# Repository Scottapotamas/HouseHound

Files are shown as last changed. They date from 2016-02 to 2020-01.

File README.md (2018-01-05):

# HouseHound

Home datalogging and display system for DIY (TCP/IP based) sensor nodes and web facing display.

I use a Raspberry Pi running OpenHAB 2 as the main hub, and then a bunch of stateless microcontroller nodes around the house interface over wifi and ethernet.

This repo contains all the applicable files for hardware, fimware, or notes for setup for each of the projects to consolidate everything, but any combination of parts should work alone. This repo is more for self-documenting the project than anything else, as keeping track of configuration is tedious.

# WeatherStation

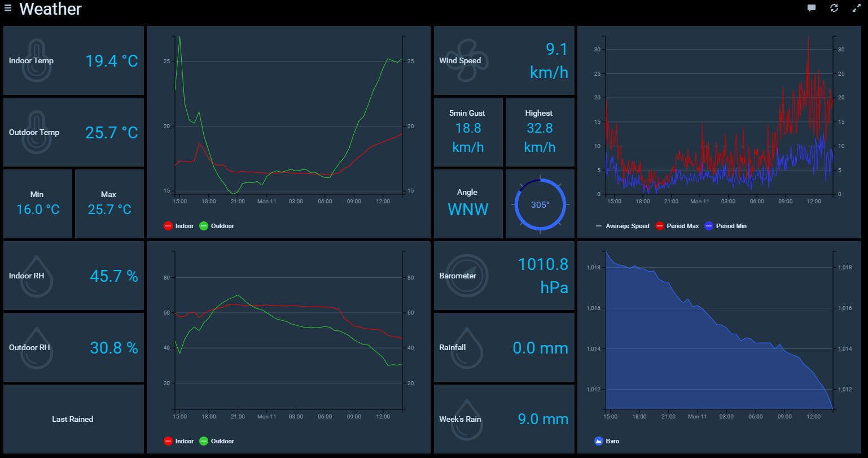
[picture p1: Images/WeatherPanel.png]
Weather WeatherStation View


Large and high feature set weather monitoring to measure the following info:
- Temperature
- Humidity
- Barometric Pressure
- Wind Speed
- Wind Direction
- Rainfall

Reference data is also scraped from the Australian BoM page for our closest station for temp/humidity references. From watching the BoM reference against local sensors, my system tracks the 'reference' data within 1°C and ~5°% RH over most days, well within the realm of local weather differences due to ~3km distance from that station.

## TempHumidityNodes

Several of these are sitting around the house to provide 2-zone indoor monitoring, and outdoor sensing.

Small and low cost Wifi Weather node for data collection, also sent to a local OpenHAB instance.

- Uses a particle photon wifi based microcontroller.
- Temperature and Humidity Sensor, includes additional spare IO for future expansion.
- Uses MQTT to send averaged temperature and humidity data to the mosquitto server.

## WeatherStation

This sits on a pole mounted to the roof. Leverages a Particle Photon wireless microcontroller and the Sparkfun weather shield to simplify connections to the hardware. Uses interrupts for rain/wind speed events, and polls other sensors periodically.

Sensors are sampled at 100ms, and averaged across the time between messages to the openHAB server for persistance and processing.

We send temperature, humidity, rainfall accumulated, windspeed and wind direction every few seconds, and track long term averages of wind speed and baro for lower noise. The short term values are shown for more responsive dashboards, while the internally averaged min/max values are logged for graphing and stats use.

MQTT is once again used to send the values to the mosquitto broker, which the OpenHAB instance subscribes to.

# PowerMonitor

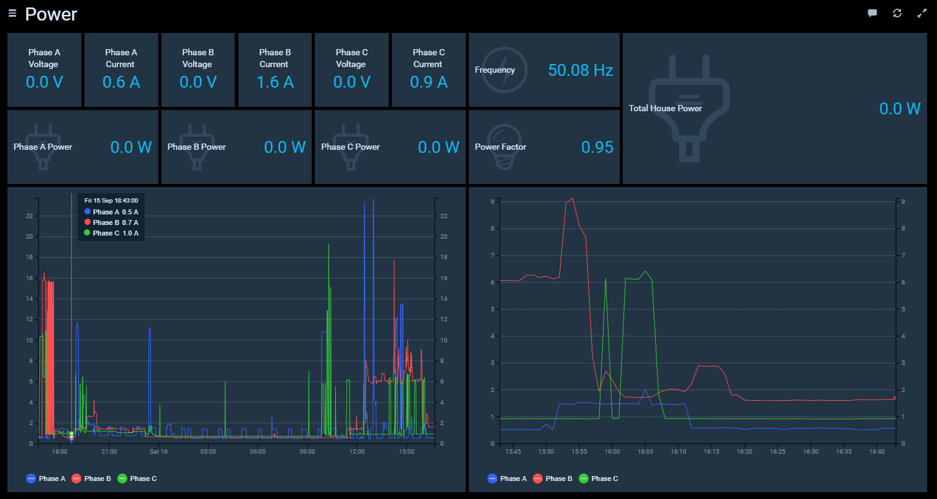
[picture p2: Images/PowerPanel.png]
Power PowerStation View


A bunch of current transducers and 3 12VAC transformers in the sub-distro board. This allows for monitoring of the voltage and current of each phase (have 3-phase installed).

Sends data to local MQTT broker as done with other sensors.

Measures:
- 3-phase current 
- 3-phase Voltage
- Power factor
- Frequency

# Airconditioner Controller

IN PROGRESS

Replacement control module for the evaporative aircon unit. Provides better information display, finer grained control of hardware, intelligent modes.

I pull data from a local OpenHAB instance for another weather node in the house, and scrapped internet weather info.
HAB node also provides some level of control for home automation.

Uses following hardware:
- Adafruit HUZZAH ESP-12E module
- HDC1000 temp and humidity sensor
- BMP280 pressure sensor
- SSD1306 2.7inch OLED (on i2c)
- WS2812 (RGBW) as a status lamp

# WaterMonitor

Sensors to monitor the status of the rain water tanks and pump system.
With a known tank level and flow information over a daily/weekly time period it should be possible to predict time-to-empty.

Measures:
- Water level in the tank using a submerged pressure sensor.
- Water flow from tank (TODO).

## Tank Level

Uses a $60 Aliexpress sourced 'stainless' 4-20mA pressure sensor, a particle photon and a ADS1115 ADC breakout from adafruit as these were just spares I had on hand. The particle and ADC are powered with a small pololu 500mA 5V SMPS which was spare.

Threw a couple of 100uF electro's on the supplies for stability, and put it in a waterproof box for outdoor use with an old phone charger to supply 12ish volts.

A gland was used to draw the pressure sensor's cable from the tank.

Because the sensor is a 4-20mA loop device, I use the ADC in differential mode across a 220R resistor wit

Eventually I'd like to add the ability to switch the feed valve from the rain collection sump to allow user controllable bypass of the tanks, so the first few mm of rain are purged and we don't put the accumulated dirt from the roof into the tanks. After manual implementation, may consider doing this automatically or semi-autonomously based on rain data.

A AC powered rotary valve with DN40 fittings was purchased from Aliexpress to test with this.

# Other OpenHAB integration

The openhab server uses HabPanel for most visualisation, which is viewed on a older Microsoft surface in fullscreen mode.

The server performs hourly speedtest.net tests and logs/graphs down/up/ping. SMNP integration to read wifi/nas utilisation is also planned.

Todo:

- Integrate with Chromecasts for control over music/tv outputs.
- Connect the burglar alarm RS232 to gain access to PIR and state information?
- Add solenoid control to the side gate

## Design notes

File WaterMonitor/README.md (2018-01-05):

# WaterMonitor

Uses particle photon, ADS1115 ADC and 220R resistor as burden for the 4-20mA pressure sensor from Aliexpress.

Samples every 250ms, averages samples over 5 seconds and publishes to the MQTT server every 5 seconds.

This is overkill and over-accurate in every aspect.

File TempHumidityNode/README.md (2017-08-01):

# Temp and Humidity Node

This node is built with a Particle Photon and a Si7021 i2c based temperature and humidity IC.

Uses MQTT to report to the MQTT/Openhab server.

These boards are design to be as simple and fast to deploy as possible. Idea is to drop one at each end of the house, and one or two outside.

# Self-heating (or lack of)

The particle photon generates lots of heat when connected to wifi. This causes a self-heating effect on the weathershield which uses the same sensor.

As these are wired directly, the sensor is on about 100mm of free cable which will allow flexibility in isolating the sensor from the photon.

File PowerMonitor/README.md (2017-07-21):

# PowerMonitor

This node is built with a Particle Photon and a ATM90E36 board bought from whatnick's tindie page.

Uses MQTT to report to the MQTT/Openhab server.

This was a fast turn-key approach to sampling 3 phase power and current, and should be better than the previous install.

Bits borrowed from https://github.com/whatnick/ATM90E36_Arduino with modifications for Photon SPI.

# Calibration

Need to calibrate against Fluke current clamp. Left it at work by accident...

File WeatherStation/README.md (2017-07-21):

# WeatherStation

This node is built with a Particle Photon and a Sparkfun Weather shield.

Uses MQTT to report to the MQTT/Openhab server.

This was a fast turn-key approach to sampling wind, rainfall and wind direction.

Code is somewhat verbose. Bits borrowed from https://github.com/rpurser47/weatherstation with some restructuring.

# Self-heating

The particle photon generates lots of heat when connected to wifi. This causes a self-heating effect which is measured by the temp sensor.

I attempted to reduce the effects by manually controlling the photon's wifi and putting it to sleep between report periods.
Turns out the ubiquiti wifi access point doesn't like a device re-connecting every 5 seconds for days, so this ended up not working.

The sensor's data is really just used for the external sensors on the roof, and barometric pressure.

# TODO

There is a lot of cross-coupled noise between the wind speed and rain reed-switch lines. The actual sensors are on a very long cable.

Need to put a scope on the lines, determine suitable software debounce parameters or beef up the sparkfun board circuitry. Would have been nice for Sparkfun to drive the switches at VCC level, then translate back to 3v3 for the micro.

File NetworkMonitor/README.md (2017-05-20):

#Network Monitoring

The plan is to do regular speedtests to watch down/up speed over time, and monitor internal hardware.

# Internet

It seems internet tests are already a solved issue:
https://community.openhab.org/t/speedtest-cli-internet-up-downlink-measurement-integration/7611

This has been implemeted.

# SNMP Network

The modem, ubiquiti wireless AP, and QNAP nas all support SNMP monitoring.

Ideally wireless speeds and states, along with storage and qnap load would be shown.

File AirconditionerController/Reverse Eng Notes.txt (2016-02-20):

# Evaporative Airconditioner Controller replacement/upgrade Project

#Existing controller
It has buttons for on/off, mode, fan, water pump, timer, and leds above them to denote the status.

The unit connects to the controller with 4 wires.
GND, 5.7V (why?), the fan and pump control lines. 
Uses a 5 pin 2.54mm pitch connector, similar to KK, but locking tab in center with no keying.

Pump is 0V, or 1.8V when on
Fan is pulled high at off (to 5.7V) 
Fanspeed is controlled with a voltage output 
	(inversely proportional to fanspeed) between 1.1v (slow) and 3.2v (pretty fast, adjustable on PCB with pot)

# Hardware

We use the ESP8266 for wifi control and as the microcontroller for this airconditioner controller. 
I will be using one of the adafruit HUZZAH boards which includes a 3v3 reg, reset button and broken out pins to make life a little easier.

# Sensing
Temp+Humiditiy sensor on i2c
Barometric pressure on i2c

# Output
2.7" OLED monochrome display driven over SPI or i2c or parallel (not in this project)
WS2812 as a status lamp

# Input
4 buttons - momentary

To drive the airconditioners, the following is used:

Fan:
	DAC on the ESP is used with a opamp for level shifting
	0-3v3 from the ESP analog output, we use a gain of 1.7 to provide a maximum 5.7v output

Water Pump:
	Driven by a digital IO on the ESP. 
	LOW = 0V
	HIGH = 3v3 from ESP -> 1.8. Probably use voltage divider, or a fet if needed.

5.7V is connected to the ESP which has onboard 3v3 regulator.

# User Interface

Mode is displayed in the top left of the display	

		Off 			Nothing is happening, idle mode
		Automatic 		Looks at temperature indoors and outdoors, and controls aircon based on delta.
		Manual			User controls the unit manually

	Web connected control doesn't have a distinct mode, but just allows an override of the existing mode and settings.

Fan Speed is displayed on the second to bottom line, on the left
	Has fan symbol, followed by % fan speed.
		if fan is off, replace % with text OFF

Pump status is displayed on the bottom line, on the left
	Water drop symbol, followed by text ON, OFF or PRIME

# Status Lamp

Aircon Off
	Displays colour wheel set by the temperature delta between inside and outside.
		ie, the colour is green at equilibrium
			goes blue when colder outside
			goes red when warmer outside

Aircon On
	Fan Only
		Green solid
	Water pump only
		Pulsing Blue
	Fan with Water
		Blue solid, gets brighter with higher fan speed

Error
	Could not connect to wifi
		Pulsing white light

	Could not find/update NTP time
		Triple white blink, then wait a bit.

# Behaviour

At startup, connect to the known wifi network. Display IP address on screen for 5 seconds once connected.
Poll NTP server for most recent time, report status to monitoring sofware as required.

We have a deadband on the temperature delta between outside and indoors, and make automatic decisions based on season

	Summer
		if temperature > deadband
			Do nothing
		if temperature < deadband
			Bring colder air into house
	Winter
		if temperature > deadband
			Bring warm air through
		if temperature < deadband
			Do nothing

HOT_THRESHOLD_DEGREES	Outside temperature is hotter than inside, threshold
COLD_THRESHOLD_DEGREES	Outside temperature is colder than inside, threshold

Fan Speed will be expressed as a percentage from 0 to 100%
The function setFanSpeed(int percentage) will calculate the output voltage from a %, to drive the DAC output with a opamp.

Voltage ranges for output as follows
FAN_SPEED_MIN	3.2
FAN_SPEED_MAX	1.1

# Function prototypes

int main () {
	
	setupIO();
	initHardware();

	initWifi();
	updateTime();
	initHAB();

	while(1) {
		main();

	}

	return 0;
}

void setupIO() {
	//set pinmodes etc

	return;
}

void initHardware() {
	//init display
	//init neopixels
	//init i2c
	//contact and check for i2c sensors

	return;
}

void initWifi() {
	
	//attempt to connect to known hotspot

	//confirm connection to network by pinging gateway

	//confirm connection to internet by pinging dns server

	return;
}

void updateTime() {
	//contact NTP time server

	//if failed, contact second server

	//set time

	return;
}

void initHAB() {
	//setup local HomeAutomation stuff as required

	return;
}

void loop() {

	//run different speed loops
	everyLoop();

	if(loopCount == 2) {	//every third loop
		mediumLoop();
	}

	if(loopCount == 10) {	//every 10th loop
		slowLoop();
	}

	if(long time condition) {	//only occasionally
		glacialLoop();
	})

	//reset anything for next loop
}

void everyLoop() {
	//read button states
	//other critical monitoring tasks

	//run through the state machine?

	return;
}

void mediumLoop() {
	//update the display
	//update pixels

	return;
}

void slowLoop() {
	//get temperature

	return;
}

void glacialLoop() {
	updateTime();
	checkOnlineWeather();

	return;
}

void setFanSpeed(int percentage) {
	//we drive the analog output to set the speed from 3.2 to 1.1V

	float driveVoltage = FAN_VOLTAGE_OFF;	

	//map percentage to voltage between 1.1 and 3.2, inversely proportional
	//apply gain of 1.7 
	//desired voltage output
	//clamp to min/max to prevent damage

	//map voltage output into 10bit
	//analogWrite(outputVal)

	return;
}

void setPump(bool enable) {
	//water pump takes 0 for off, 1.8v for on.
	
	//digitalWrite(PUMP_PIN, enable);

	if(fanSpeed > 5) {	//fan on
		//start the pump or leave it on, log as needed.
		//state = wetfan;
	} else {	//fan not running
		//we are priming the pump first
		//state = priming;
	}

	return;
}
]

void readSensors() {
	
	//get temperature

	//get humidity

	//get barometric pressure

	//push this new data to HAB server

	return;
}

void getExternalTemp() {
	//contact HAB server and request a temperature from a different node
	//save to internal variable

	return;
}

void checkOnlineWeather() {
	//contact/poll some service for forcast weather
	//update structure as required

	return;
}

void drawDisplay() {
	
	//draw current mode text
	drawFanItem();
	drawPumpItem();

	//draw current time

	//draw time since start
	//draw scheduled off time

	switch(tempPage) {	//draw the corresponding temperature data
		case 0:
			//draw text "Inside"

			//draw internal temp, humidity

			break;
		case 1:
			//draw text "Exterior"

			//draw local external temp, humidity

			break;

		case 2:
			//draw text "Internet"

			//draw internet temp/humidity

			break;
	}

	return;
}

void drawFanItem() {
	
	//draw fan icon

	if(fanSpeed > 5) {
		//percentage text

	} else {
		//off text

	}

	return;
}

void drawPumpItem() {
	
	//draw water drop symbol

	//draw pump status

	return;
}

void updateStatusLED(int ledTypeStruct) {
	
	switch(ledTypeStruct) {
		case 0:		//off

		break;

		case 1:		//auto mode
			//lamp changes temperature based on temp differential outside house

		break;

		case 2.1:		//manual mode fan only
			//light is green, brightness controlled by fan speed.

		break;

		case 2.2:		//manual mode water only
			//priming pump, pulse blue

		break;

		case 2.3:		//manual mode fan with water
			//blue light, brightness controlled by fan speed.

		break;

		case 3.1:		//waiting for scheduled start
			//pulse white

		break;

		case 3.2:		//running until scheduled stop
			//white

		break;

		default:	//something went wrong
			//flash white error code

		break;

	}

	return;
}

void setBrightnessByPercent(int percentage) {
	//we compensate for linear/log luma output

	//https://ledshield.wordpress.com/2012/11/13/led-brightness-to-your-eye-gamma-correction-no/

	brightness_mod = magic multiplier value;
	
	return;
}

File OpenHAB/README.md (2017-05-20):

# OpenHAB Notes

Setup a OpenHAB 2 install on a Pi2.

# General notes for myself

- Changed the timezone and local to Adelaide etc.
- Changed the default password and samba password, still using openhabian as the user
- Configured mosquitto as the MQTT broker
- Tested the mqtt server using MQTT.fx on windows

- Assigned the pi to 192.168.1.100 via DHCP reservation.
- Mount the samba share and edit config files as required. WebUI seems painful to use.

- Hostname is househound now instead of openhabian.
- Port 8080 has the webUI for OpenHAB.

- In the mqtt.cfg config file, 192.168.1.100:8083 was set as the broker URI for the mosquitto install done earlier.

# Persistance Setup

Using mySQL for persistence of data. Database is Openhab, user is openhab with standard password.

- Temp/Humidity and Pressure are logged at 30min interval.
- Rainfall is logged on every update as each update represents non-zero rainfall over the sampling period.
- A series of persistance periods are added. Need to work out what to use for each dataset.

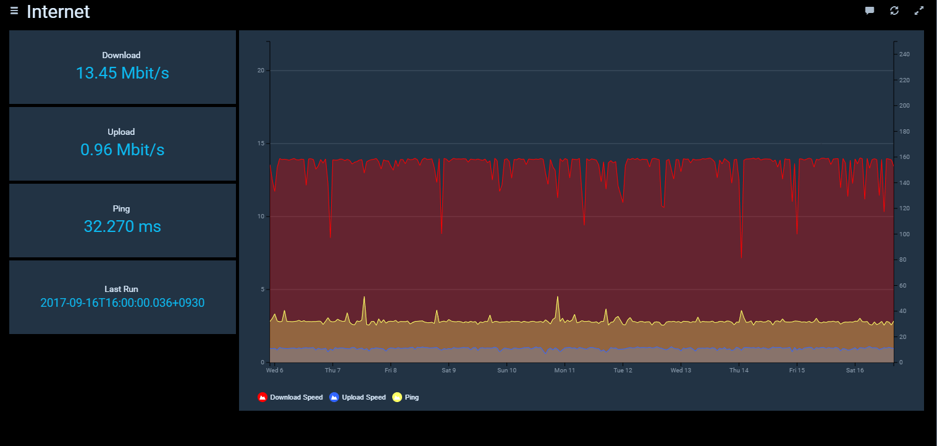
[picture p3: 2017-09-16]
Images/InternetPanel.png

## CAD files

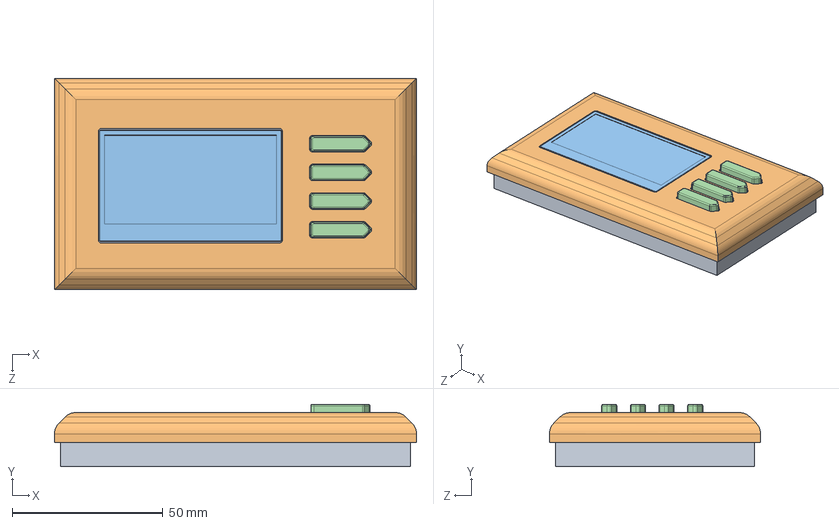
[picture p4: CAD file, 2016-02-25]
AirconditionerController/CAD/Controller Assembly.SLDASM
120.0 x 20.7 x 70.0 mm
Backing Piece
Faceplate
Display
Button x 4

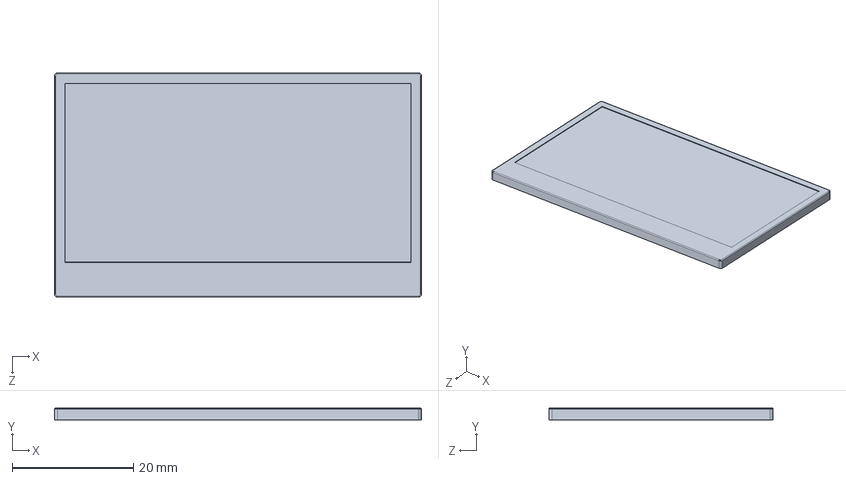
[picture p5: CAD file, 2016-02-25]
AirconditionerController/CAD/Display.SLDPRT
60.5 x 2.00 x 37.0 mm

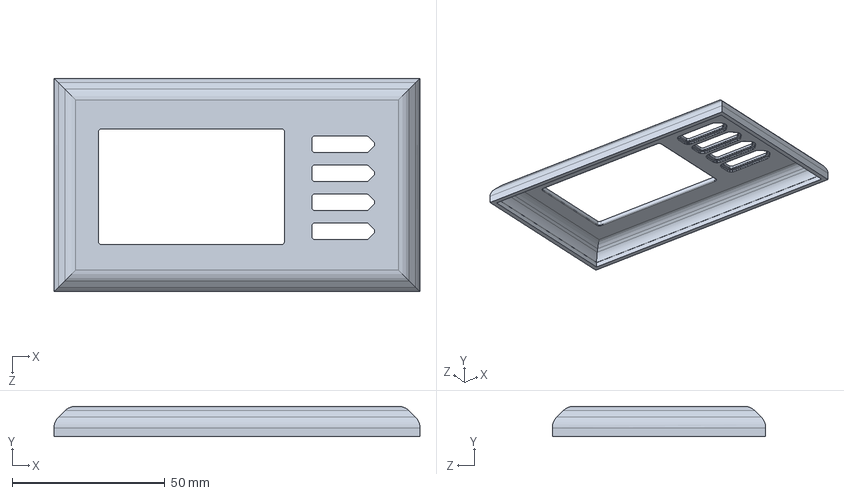
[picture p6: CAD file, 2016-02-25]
AirconditionerController/CAD/Faceplate.SLDPRT
120.0 x 10.0 x 70.0 mm

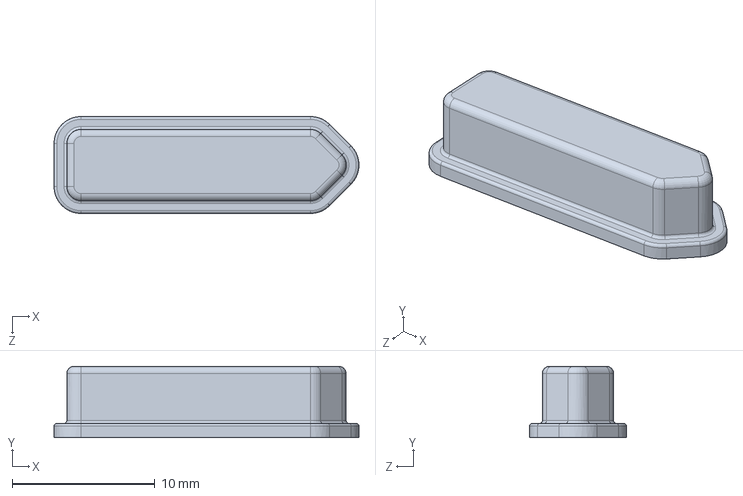
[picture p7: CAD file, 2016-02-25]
AirconditionerController/CAD/Button.SLDPRT
21.4 x 5.00 x 6.80 mm

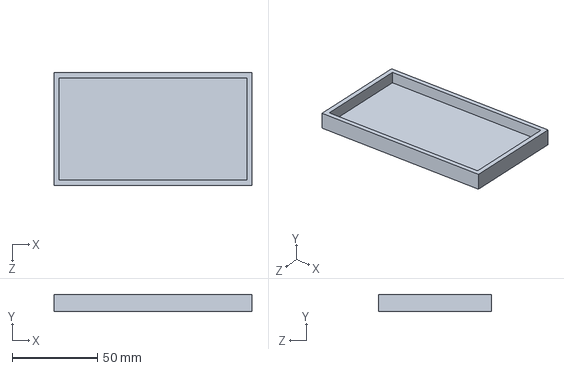
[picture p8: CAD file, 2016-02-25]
AirconditionerController/CAD/Backing Piece.SLDPRT
116.0 x 10.0 x 66.0 mm

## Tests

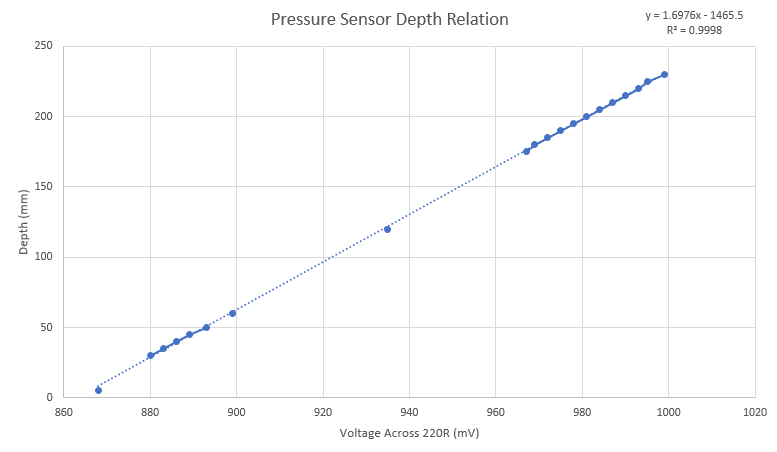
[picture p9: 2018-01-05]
Images/DepthCalibrationCurve.PNG

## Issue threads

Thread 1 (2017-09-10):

Rain detection isn't filtered properly

Scottapotamas, 2017-09-10:
Rain detections with Sparkfun weather stick (windspeed/direction and rain gauge) were firing random events of noise causing phantom rainfall measures.

Scope on the D2 and D3 pins of the photon, watching for falling edges on D2 (rain).

Some noise would occasionally cause a ~10-20us low spike with lots of ringing, and the falling edges are caught by the interrupt on the micro. Subsequent falling edges in this fake event weren't measured due to the debounce on the interrupt event handler, but on reflection, the actual duration of the 'switch closure' has no lower bound.

Solution: watch or monitor interrupt on falling AND rising edge, and ensure that the pulse is longer than a few milliseconds to remove these occasional noisy events.

Check to see if the photon can have rising/falling/change interupts on the same pin, otherwise, connect to two pins and use different interrupt handlers, or just sample the pin's state after a edge has been spotted...

Closed 2017-09-24.

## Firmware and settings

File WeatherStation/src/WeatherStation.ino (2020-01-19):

/*
* Project WeatherStation
* Description:  Uses sparkfun photon weather board with sparkfun weather station.
*               Which includes anemometer, wind vane, and rain meter.
* Author: Scott Rapson,
          sensor interface code from Sparkfun,
          wind/rain interface code adapted from https://github.com/rpurser47/weatherstation
* Date:   March 2017
*/

#include "SparkFun_Photon_Weather_Shield_Library.h"
#include <math.h>
#include <RunningMedian.h>
#include "MQTT.h"
#include "SparkFun_AS3935.h"

#define SENSOR_SAMPLE_TIME_MS 500 // poll sensors internally every X milliseconds

#define PUBLISH_RATE_TEMP_S 17        // Publish sensor data at the broker every X seconds
#define PUBLISH_RATE_WIND_S 5
#define PUBLISH_RATE_RAIN_S 22
#define PUBLISH_RATE_LIGHTNING_S 8

#define PUBLISH_RATE_TEMP_MS (PUBLISH_RATE_TEMP_S*1000)       //seconds into msec
#define PUBLISH_RATE_WIND_MS (PUBLISH_RATE_WIND_S*1000)
#define PUBLISH_RATE_RAIN_MS (PUBLISH_RATE_RAIN_S*1000)
#define PUBLISH_RATE_LIGHTNING_MS (PUBLISH_RATE_LIGHTNING_S*1000)


#define LONG_TERM_AVERAGE_M 5
#define LONG_TERM_BUFFER_SIZE ((LONG_TERM_AVERAGE_M*60)*(1000/SENSOR_SAMPLE_TIME_MS))  // (number of seconds to buffer) * (samples added per second)

// Timers to maintain sampling and publish throttles
unsigned int timeNextSensorReading;
unsigned int timeNextPublishTemp;
unsigned int timeNextPublishWind;
unsigned int timeNextPublishRain;
unsigned int timeNextPublishLightning;

//Manage rolling buffer of windspeeds for whisker style display of speeds
RunningMedian windBuffer = RunningMedian(LONG_TERM_BUFFER_SIZE);

//SYSTEM_THREAD(ENABLED); //run code regardless of internet connection etc

void callback(char* topic, byte* payload, unsigned int length);

/**
 * if want to use IP address,
 * byte server[] = { XXX,XXX,XXX,XXX };
 * MQTT client(server, 1883, callback);
 * want to use domain name,
 * MQTT client("www.sample.com", 1883, callback);
 **/
byte server[] = { 192,168,1,100 };
MQTT client(server, 1883, callback);

// recieve message
void callback(char* topic, byte* payload, unsigned int length) {
    char p[length + 1];
    memcpy(p, payload, length);
    p[length] = NULL;
    delay(1000);
}

void setup()
{
  client.connect("weatherstation");

  // publish/subscribe
  if (client.isConnected())
  {
    client.publish("debug/weatherstation","Starting Up");
  }

   //setup the sensing and calculation functions
   initializeTempHumidityAndPressure();
   initializeRainGauge();
   initializeAnemometer();
   initializeWindVane();
   initializeLightning();

   // Schedule the next sensor reading and publish events
   timeNextSensorReading  = millis() + SENSOR_SAMPLE_TIME_MS;

   timeNextPublishTemp    = millis() + PUBLISH_RATE_TEMP_MS;
   timeNextPublishWind    = millis() + PUBLISH_RATE_WIND_MS;
   timeNextPublishRain    = millis() + PUBLISH_RATE_RAIN_MS;
   timeNextPublishLightning = millis() + PUBLISH_RATE_LIGHTNING_MS;
}

void loop()
{
  processRainEvents();  //handle rain

  // Sample sensors that need to be polled (temp, humidity, pressure, wind vane)
  // The rain and wind speed sensors use interrupts to catch reed switch closures
  if( timeNextSensorReading <= millis() )
  {
     captureTempHumidityPressure();
     captureWindVane();

     // Schedule the next sensor reading
     timeNextSensorReading = millis() + SENSOR_SAMPLE_TIME_MS;
  }

  // Publish the data collected to MQTT
  publishData();

  //connect to network
  if( client.isConnected() )
  {
    client.loop();
  }
  else
  {
    client.connect("weatherstation");
  }
}

/*void publishToParticle(float tempC, float humidityRH, float pressureKPa, float rainMillimeters, float windKMH, float gustKMH, float windDegrees)
{
   Particle.publish("weather",
                       String::format("%0.1fC, %0.0f%%, %0.0fhPa, %0.2fmm, Avg:%0.0fkmh, Gust:%0.0fkmh, Dir:%0.0f deg.",
                           tempC, humidityRH, pressureKPa, rainMillimeters, windKMH, gustKMH, windDegrees), 60 , PRIVATE);
}*/

// Decide what to publish and when
void publishData( void )
{
  if( timeNextPublishTemp <= millis() )
  {
     // Get the data to be published
     float tempC        = getAndResetTempC();
     float humidityRH   = getAndResetHumidityRH();
     float pressureKPa  = (getAndResetPressurePascals() / 100.0) + 5.4;

     publishToMQTTTempHumidity( tempC, humidityRH, pressureKPa );

     // Schedule the next publish event
     timeNextPublishTemp    = millis() + PUBLISH_RATE_TEMP_MS;
  }

  if( timeNextPublishWind <= millis() )
  {
     float windKMH = getAndResetAnemometerKMH();
     windBuffer.add(windKMH); //add the latest reading to the buffer

     publishToMQTTWind( windKMH, windBuffer.getAverage(), windBuffer.getLowest(), windBuffer.getHighest(), getAndResetWindVaneDegrees() );
     timeNextPublishWind    = millis() + PUBLISH_RATE_WIND_MS;
  }

  if( timeNextPublishRain <= millis() )
  {
    publishToMQTTRain( getAndResetRainMillimeters() );
    timeNextPublishRain    = millis() + PUBLISH_RATE_RAIN_MS;
  }

  if( timeNextPublishLightning <= millis() )
  {
    publishToMQTTLightning( getAndResetLightningStrikes(), getAndResetLightningDistance(), getAndResetLightningIntensity() );
    timeNextPublishLightning    = millis() + PUBLISH_RATE_LIGHTNING_MS;
  }

}

int publishToMQTTTempHumidity(float tempC, float humidityRH, float pressureKPa )
{
  int publish_successes = 0;

  //client.publish returns 0 if failed, >=1 if success
  publish_successes += client.publish("enviro/temperature", String(tempC));
  publish_successes += client.publish("enviro/pressure",    String(pressureKPa));
  publish_successes += client.publish("enviro/humidity",    String(humidityRH));

  return publish_successes;
}

int publishToMQTTWind( float windKMH, float averageWind, float minWind, float maxWind, int windDegrees )
{
  int publish_successes = 0;

  publish_successes += client.publish("enviro/windKMH",       String(windKMH));
  publish_successes += client.publish("enviro/windAverage",   String(averageWind));
  publish_successes += client.publish("enviro/windMin",       String(minWind));
  publish_successes += client.publish("enviro/windMax",       String(maxWind));
  publish_successes += client.publish("enviro/windAngle",     String(windDegrees));

  return publish_successes;
}

int publishToMQTTRain( float rainMillimeters )
{
  int publish_successes = 0;

  publish_successes += client.publish("enviro/rainMillimeters", String(rainMillimeters));

  return publish_successes;
}

int publishToMQTTLightning( int lightningStrikes, int lightningDistance, int lightningEnergy )
{
  int publish_successes = 0;

  publish_successes += client.publish("enviro/lightningStrikes",    String(lightningStrikes));
  publish_successes += client.publish("enviro/lightningDistance",   String(lightningDistance));
  publish_successes += client.publish("enviro/lightningIntensity",  String(lightningEnergy));

  return publish_successes;
}

//===========================================================
// Temp, Humidity and Pressure
//===========================================================
// The temperature, humidity, and pressure sensors are on board
// the weather station board, and use I2C to communicate.  The sensors are read
// frequently by the main loop, and the results are averaged over the publish cycle

//Create Instance of HTU21D or SI7021 temp and humidity sensor and MPL3115A2 barometric sensor library by Sparkfun
Weather sensor;

float         humidityRHTotal             = 0.0;    //sum of percent %
unsigned int  humidityRHReadingCount      = 0;      //num samples
float         tempCTotal                  = 0.0;    //sum of temps in C
unsigned int  tempCReadingCount           = 0;      //num samples
float         pressurePascalsTotal        = 0.0;    //sum of pressure in P
unsigned int  pressurePascalsReadingCount = 0;      //num samples

void initializeTempHumidityAndPressure()
{
   //Initialize the I2C sensors, and set modes as required
   sensor.begin();
   sensor.setModeBarometer();
   sensor.setOversampleRate(7);
   sensor.enableEventFlags();  //Necessary register calls to enble temp, baro and alt
   return;
}

// Read the humidity and pressure sensors, and update the running average
void captureTempHumidityPressure()
{
  // Measure Relative Humidity and temperature from the HTU21D or Si7021
  float humidityRH = sensor.getRH();
  float tempC = sensor.getTemp();

  //Measure Pressure from the MPL3115A2
  float pressurePascals = sensor.readPressure();

  //Include humidity reading in running mean if within reasonable bounds
  if( humidityRH > 0 && humidityRH < 110 ) // Supersaturation humidity levels over 100% are possible
  {
    humidityRHTotal += humidityRH;
    humidityRHReadingCount++;
  }

  //Include temperature reading in running mean if within reasonable bounds
  if( tempC > -20 && tempC < 80 )
  {
    tempCTotal += tempC;
    tempCReadingCount++;
  }

  //Include pressure reading in running mean if within reasonable bounds
  if( pressurePascals > 80000 && pressurePascals < 110000 )
  {
    pressurePascalsTotal += pressurePascals;
    pressurePascalsReadingCount++;
  }

  return;
}

float getAndResetTempC()
{
   if( tempCReadingCount == 0 )
   {
       return 0;
   }

   float result       = tempCTotal / float( tempCReadingCount );
   tempCTotal         = 0.0;
   tempCReadingCount  = 0;

   return result;
}

float getAndResetHumidityRH()
{
   if( humidityRHReadingCount == 0 )
   {
       return 0;
   }

   float result = humidityRHTotal / float( humidityRHReadingCount );
   humidityRHTotal = 0.0;
   humidityRHReadingCount = 0;

   return result;
}

float getAndResetPressurePascals()
{
   if( pressurePascalsReadingCount == 0 )
   {
       return 0;
   }

   float result = pressurePascalsTotal / float( pressurePascalsReadingCount );
   pressurePascalsTotal = 0.0;
   pressurePascalsReadingCount = 0;

   return result;
}

//===========================================================================
// Rain Gauge
//===========================================================================
int RainPin = D2;

//interrupt edge counting
volatile unsigned int rainEventCount;
unsigned int          lastRainEvent;

//track the times when we have rising and falling edges, validate closure timing
unsigned int          timeTipStart;
unsigned int          timeTipStop;
unsigned int          validatedRainEvents;
int                   rainMinEventDuration = 25;  //msec of low time for valid pulse
int                   rainMaxEventDuration = 300;  //msec of low time for valid pulse

//unit conversions per valid pulse
float                 RainScaleInches = 0.022; // Datasheet: Pulse = .011 inches of rain
float                 RainScaleMillimeters = 0.5588; // From imperial value

void initializeRainGauge()
{
  pinMode( RainPin, INPUT_PULLUP );

  rainEventCount = 0;
  lastRainEvent = 0;

  timeTipStart = 0;
  timeTipStop = 0;
  validatedRainEvents = 0;

  attachInterrupt( RainPin, handleRainEvent, CHANGE );

  return;
}

void processRainEvents()
{
  //we get a count of debounced rain edges which can be either rising or falling
  //if this count is non-zero, there is a valid (unknown polarity edge) we need to catch
  if( rainEventCount > 0 )
  {
    rainEventCount = 0; //reset the edge counter
    int bucketNotTipped = digitalRead(RainPin); //check reed state. Goes low when tipping

    if( bucketNotTipped ) //we are in an 'idle switch' state and probably saw a rising edge
    {
      if( timeTipStart != 0 ) //we've seen a falling edge already
      {
        timeTipStop = millis();
      }
    }
    else  //bucket is in the process of being tipped, saw a falling edge(s)
    {
      if( timeTipStart == 0)  //first time we've seen it low
      {
        timeTipStart = millis();
        timeTipStop = 0;
      }
    }
  }

  //we've seen a falling and rising edge, and the falling is older than rising
  if( timeTipStop != 0 && timeTipStop > timeTipStart )
  {
    unsigned int edgeWidth = timeTipStop - timeTipStart;

    if( edgeWidth >= rainMinEventDuration && edgeWidth <= rainMaxEventDuration )
    {
      validatedRainEvents++;  //increase valid rain switch closures count
    }

    timeTipStart  = 0;  //zero the width timing vars
    timeTipStop   = 0;
  }
}

void handleRainEvent()
{
   unsigned int timeRainEvent = millis(); // grab current time

   // debounce 5ms for rapid repeated edges such as ringing with long cables
   if( timeRainEvent - lastRainEvent < 5 )
   {
     return;
   }

   rainEventCount++; //Increase this minute's amount of rain
   lastRainEvent = timeRainEvent; // set up for next event
}

float getAndResetRainMillimeters()
{
   float result = RainScaleMillimeters * float( validatedRainEvents );
   validatedRainEvents = 0;

   return result;
}

//===========================================================================
// Wind Speed (Anemometer)
//===========================================================================

// The Anemometer generates a frequency relative to the windspeed.  1Hz: 1.492MPH, 2Hz: 2.984MPH, etc.
// We measure the average period (elaspsed time between pulses), and calculate the average windspeed since the last recording.
int AnemometerPin = D3;
float AnemometerScaleMPH = 1.492; // Datasheet: Imperial Windspeed for 1Hz pulses
float AnemometerScaleKMH = 2.4011; // Metric equiv of above

volatile unsigned int AnemoneterPeriodTotal         = 0;
volatile unsigned int AnemoneterPeriodReadingCount  = 0;
unsigned int          lastAnemoneterEvent           = 0;

void initializeAnemometer()
{
 pinMode( AnemometerPin, INPUT_PULLUP );

 AnemoneterPeriodTotal = 0;
 AnemoneterPeriodReadingCount = 0;
 lastAnemoneterEvent = 0;

 attachInterrupt( AnemometerPin, handleAnemometerEvent, FALLING );

 return;
}

void handleAnemometerEvent()
{
   // Activated by the magnet in the anemometer (2 ticks per rotation)
    unsigned int timeAnemometerEvent = millis(); // grab current time

   //If there's never been an event before (first time), capture it
   if( lastAnemoneterEvent != 0 )
   {
       //time since last event
       unsigned int period = timeAnemometerEvent - lastAnemoneterEvent;

       // debounce <20mS readings
       if( period < 20 )
       {
         return;
       }

       AnemoneterPeriodTotal += period;
       AnemoneterPeriodReadingCount++;
   }

   lastAnemoneterEvent = timeAnemometerEvent; // set up for next event
}

float getAndResetAnemometerKMH()
{
   if( AnemoneterPeriodReadingCount == 0 )
   {
       return 0;
   }

   // Have the sum of observed periods between pulses, and number of observations.
   // Calculate the average period (sum / number of readings), take the inverse and multiply by 1000 for frequency, then mulitply by scale factor.
   // The math below is transformed to maximize accuracy by doing all muliplications BEFORE dividing.
   float result = AnemometerScaleKMH * 1000.0 * float( AnemoneterPeriodReadingCount ) / float( AnemoneterPeriodTotal );
   AnemoneterPeriodTotal = 0;
   AnemoneterPeriodReadingCount = 0;

   return result;
}

//===========================================================
// Wind Vane
//===========================================================
void initializeWindVane()
{
   return;
}

// For the wind vane, average the unit vector components (the sine and cosine of the angle)
int           WindVanePin = A0;

float         windVaneCosTotal      = 0.0;
float         windVaneSinTotal      = 0.0;
unsigned int  windVaneReadingCount  = 0;

void captureWindVane()
{
   //Read the wind vane, and update the running average of the two components of the vector
   unsigned int windVaneRaw = analogRead( WindVanePin );

   float windVaneRadians = lookupRadiansFromRaw( windVaneRaw );

   if( windVaneRadians > 0 && windVaneRadians < 6.14159 )
   {
       windVaneCosTotal += cos( windVaneRadians );
       windVaneSinTotal += sin( windVaneRadians );
       windVaneReadingCount++;
   }

   return;
}

float getAndResetWindVaneDegrees()
{
   if(windVaneReadingCount == 0)
   {
       return 0;
   }

   float avgCos = windVaneCosTotal / float( windVaneReadingCount );
   float avgSin = windVaneSinTotal / float( windVaneReadingCount );
   float result = atan( avgSin / avgCos ) * 180.0 / 3.14159;

   windVaneCosTotal = 0.0;
   windVaneSinTotal = 0.0;
   windVaneReadingCount = 0;

   // atan can only tell where the angle is within 180 degrees.
   // Need to look at cos to tell which half of circle we're in
   if( avgCos < 0 )
   {
     result += 180.0;
   }

   // atan will return negative angles in the NW quadrant
   //push those into positive space.
   if( result < 0 )
   {
     result += 360.0;
   }

  return result;
}

float lookupRadiansFromRaw(unsigned int analogRaw)
{
   // The mechanism for reading the weathervane isn't arbitrary, but just look up which of 16 position we're in.
   if( analogRaw >= 2200 && analogRaw < 2400 ) return ( 3.14 );   //South
   if( analogRaw >= 2100 && analogRaw < 2200 ) return ( 3.53 );   //SSW
   if( analogRaw >= 3200 && analogRaw < 3299 ) return ( 3.93 );   //SW
   if( analogRaw >= 3100 && analogRaw < 3200 ) return ( 4.32 );   //WSW
   if( analogRaw >= 3890 && analogRaw < 3999 ) return ( 4.71 );   //West
   if( analogRaw >= 3700 && analogRaw < 3780 ) return ( 5.11 );   //WNW
   if( analogRaw >= 3780 && analogRaw < 3890 ) return ( 5.50 );   //NW
   if( analogRaw >= 3400 && analogRaw < 3500 ) return ( 5.89 );   //NNW
   if( analogRaw >= 3570 && analogRaw < 3700 ) return ( 0.00 );   //North
   if( analogRaw >= 2600 && analogRaw < 2700 ) return ( 0.39 );   //NNE
   if( analogRaw >= 2750 && analogRaw < 2850 ) return ( 0.79 );   //NE
   if( analogRaw >= 1510 && analogRaw < 1580 ) return ( 1.18 );   //ENE
   if( analogRaw >= 1580 && analogRaw < 1650 ) return ( 1.57 );   //East
   if( analogRaw >= 1470 && analogRaw < 1510 ) return ( 1.96 );   //ESE
   if( analogRaw >= 1900 && analogRaw < 2000 ) return ( 2.36 );   //SE
   if( analogRaw >= 1700 && analogRaw < 1750 ) return ( 2.74 );   //SSE

   if(analogRaw > 4000) return(-1);     // Open circuit?  Probably means the sensor is not connected

  //  Particle.publish("error", String::format("Got %d from Windvane.", analogRaw), 60 , PRIVATE);
   return -1;
}


//===========================================================
// Lightning Detector
//===========================================================

#define AS3935_ADDR 0x03
#define AS3935_INDOOR_MODE 0x12
#define AS3935_OUTDOOR_MODE 0xE
#define AS3935_LIGHTNING_INT 0x08
#define AS3935_DISTURBER_INT 0x04
#define AS3935_NOISE_INT 0x01

int as3935_int_pin = D4;

// Configuration values
uint8_t as3935_noise_floor = 2;
uint8_t as3935_watchdog = 2;
uint8_t as3935_spike = 2;
uint8_t as3935_lightning_thresh = 1;

uint8_t as3935_int_flag = 0;

uint8_t as3935_strikes = 0;
uint8_t as3935_distance = 0;
uint16_t as3935_energy = 0;

enum {
  INT_NOISE,
  INT_DISTURBANCE,
  INT_LIGHTNING,
} LightningInterruptEvent_t;

SparkFun_AS3935 lightning(AS3935_ADDR);

void initializeLightning()
{
  pinMode( as3935_int_pin, INPUT );

  if( !lightning.begin() )
  {
    // Report error
    Particle.publish("error", String::format("Couldn't start AS3935 lightning detector"), 60 , PRIVATE);
  }

  attachInterrupt( as3935_int_pin, handlLightningEvent, RISING );

  // Don't interrupt on artificial strikes
  lightning.maskDisturber(true);

  // Get indoor/outdoor modes
  //int enviVal = lightning.readIndoorOutdoor();

  // Set noise floor from 1-7 lowest-highest. Default 2
  lightning.setNoiseLevel(as3935_noise_floor);

  // Set watchdog value between 1-10 lowest-highest. Default 2
  lightning.watchdogThreshold(as3935_watchdog);

  // Spike rejection from 1-11, lowest-highest. Default 2.
  // Value represents shape validation routine. See datasheet.
  lightning.spikeRejection(as3935_spike);

  // Lightning interrupt based on number of detected strikes
  // Default is 1, Takes 1, 5, 9, 16
  lightning.lightningThreshold(as3935_lightning_thresh);

}

int getAndResetLightningStrikes()
{
  int strike_count = as3935_strikes;
  as3935_strikes = 0;

  return strike_count;
}

int getAndResetLightningDistance()
{
  int strike_distance = as3935_distance;
  as3935_distance = 0;

  return strike_distance;
}

int getAndResetLightningIntensity()
{
  int strike_intensity = as3935_energy;
  as3935_energy = 0;

  return strike_intensity;
}

void handlLightningEvent()
{
  // Got an interrupt from the lightning detector, identify the cause
  as3935_int_flag = lightning.readInterruptReg();

  switch( as3935_int_flag )
  {
    case INT_NOISE:
      // Discard
    break;

    case INT_DISTURBANCE:
      // Discard
    break;

    case INT_LIGHTNING:
      // Count this latest strike
      as3935_strikes += as3935_lightning_thresh;

      // Calculated distance to the storm, IC calculates based on 15-minute observation window
      as3935_distance = lightning.distanceToStorm();

      // Unitless intensity value
      as3935_energy = lightning.lightningEnergy();
    break;

    default:
      //wut
      break;
  }
}

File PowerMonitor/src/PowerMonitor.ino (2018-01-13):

/* ATM90E36 Energy Monitor

  Uses a ATM90E36 breakout board by whatnick fron Tindie.
  Uses MQTT to talk to OpenHab system for power logging/graphing.
  Borrowed bits of their (whatnick and Ryzee)'s library for interfacing, and adapted to Photon.

  Scott Rapson - 2017
*/

#define SoftReset   0x00    //Software Reset
#define SysStatus0  0x01    //System Status0
#define SysStatus1  0x02    //System Status1
#define FuncEn0     0x03    //Function Enable0
#define FuncEn1     0x04    //Function Enable1
#define SagTh       0x08    //Voltage Sag Threshold
//#define SmallPMod   0x04  //Small-Power Mode
#define LastSPIData 0x0F  //Last Read/Write SPI Value
//#define LSB         0x08        //RMS/Power 16-bit LSB

#define ConfigStart 0x30    //Configuration start command
#define PLconstH  0x31      //High Word of PL_Constant
#define PLconstL  0x32      //Low Word of PL_Constant
#define MMode0    0x33      //Metering Mode Configuration
#define MMode1    0x34      //Metering Mode Configuration
#define PStartTh  0x35      //Active Startup Power Threshold
#define QStartTh  0x36      //Reactive Startup Power Threshold
#define CSZero    0x3B	    //Checksum 0

#define CalStart  0x40     //Calibration Start Command
#define PoffsetA  0x41     //L Line Active Power Offset
#define QoffsetA  0x42     //L Line Reactive Power Offset
#define PoffsetB  0x43     //L Line Active Power Offset
#define QoffsetB  0x44     //L Line Reactive Power Offset
#define PoffsetC  0x45     //L Line Active Power Offset
#define QoffsetC  0x46     //L Line Reactive Power Offset
#define GainA     0x47     //A Line Calibration Gain
#define PhiA      0x48     //A Line Calibration Angle
#define GainB     0x49     //B Line Calibration Gain
#define PhiB      0x4A     //B Line Calibration Angle
#define GainC     0x4B     //C Line Calibration Gain
#define PhiC      0x4C     //C Line Calibration Angle
#define CSOne     0x4D     //Checksum 1

#define AdjStart  0x60     //Measurement Calibration Start Command
#define UgainA    0x61     //A Voltage rms Gain
#define IgainA    0x62     //A Line Current rms Gain
#define UgainB    0x65     //B Voltage rms Gain
#define IgainB    0x66     //B Line Current rms Gain
#define UgainC    0x69     //C Voltage rms Gain
#define IgainC    0x6A     //C Line Current rms Gain
#define UoffsetA  0x63     //Voltage Offset
#define UoffsetB  0x67     //Voltage Offset
#define UoffsetC  0x6B     //Voltage Offset
#define IoffsetA  0x64     //L Line Current Offset
#define IoffsetB  0x68     //N Line Current Offse
#define IoffsetC  0x6C     //N Line Current Offse
#define CSThree   0x6F     //Checksum 3

#define APenergyA 0x81    //Forward Active Energy
#define APenergyB 0x82    //Forward Active Energy
#define APenergyC 0x83    //Forward Active Energy
#define ANenergyA 0x85    //Reverse Active Energy
#define ANenergyB 0x86    //Reverse Active Energy
#define ANenergyC 0x87    //Reverse Active Energy
#define ANenergyT 0x84    //Absolute Active Energy
#define RPenergyA 0x89    //Forward (Inductive) Reactive Energy
#define RPenergyB 0x8A    //Forward (Inductive) Reactive Energy
#define RPenergyC 0x8B    //Forward (Inductive) Reactive Energy
#define RnenergyA 0x8D    //Reverse (Capacitive) Reactive Energy
#define RnenergyB 0x8E    //Reverse (Capacitive) Reactive Energy
#define RnenergyC 0x8F    //Reverse (Capacitive) Reactive Energy
#define RPenergyT 0x88    //Absolute Reactive Energy
#define EnStatus0 0x95    //Metering Status
#define EnStatus1 0x96    //Metering Status
#define IrmsA     0xDD    //L Line Current rms A
#define IrmsB     0xDE    //L Line Current rms B
#define IrmsC     0xDF    //L Line Current rms C
#define UrmsA     0xD9    //Voltage rms A
#define UrmsB     0xDA    //Voltage rms B
#define UrmsC     0xDB    //Voltage rms C

#define PmeanT 0xB0     //Total Mean Active Power
#define PmeanA 0xB1     //A Line Mean Active Power
#define PmeanB 0xB2     //B Line Mean Active Power
#define PmeanC 0xB3     //C Line Mean Active Power
#define QmeanA 0xB5     //A Line Mean Reactive Power
#define QmeanB 0xB6     //B Line Mean Reactive Power
#define QmeanC 0xB7     //C Line Mean Reactive Power
#define SmeanA 0xB9     //A Line Mean Apparent Power
#define SmeanB 0xBA     //B Line Mean Apparent Power
#define SmeanC 0xBB     //C Line Mean Apparent Power
#define PFmeanT 0xBC    //Mean Power Factor

#define Freq    0xF8    //Voltage Frequency
#define PangleA 0xF9    //Phase Angle between Voltage and A Line Current
#define PangleB 0xFA    //Phase Angle between Voltage and B Line Current
#define PangleC 0xFB    //Phase Angle between Voltage and C Line Current

#include "MQTT.h"
#define SENSOR_SAMPLE_TIME_MS 1000
#define PUBLISH_RATE_S 5
#define PUBLISH_RATE_MS (PUBLISH_RATE_S*1000) //seconds into msec

// Timers to maintain sampling and publish throttles
unsigned int timeNextSensorReading;
unsigned int timeNextPublish;

void callback(char* topic, byte* payload, unsigned int length);

/**
 * if want to use IP address,
 * byte server[] = { XXX,XXX,XXX,XXX };
 * MQTT client(server, 1883, callback);
 **/
byte server[] = { 192,168,1,100 };
MQTT client(server, 1883, callback);

// recieve message
void callback(char* topic, byte* payload, unsigned int length)
{
    char p[length + 1];
    memcpy(p, payload, length);
    p[length] = NULL;

    delay(1000);
}

void setup()
{
  /* Initialize the serial port to host */
  Serial.begin(115200);

  client.connect("PowerMonitor");
  // publish/subscribe
  if (client.isConnected())
  {
      client.publish("debug/powermonitor","Starting Up");
  }

  /*Initialise the ATM90E36 + SPI port */
  InitEnergyIC();

  timeNextSensorReading  = millis() + SENSOR_SAMPLE_TIME_MS;
  timeNextPublish        = millis() + PUBLISH_RATE_MS;
}
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

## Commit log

2016-02-19 Added icons for water and fan
2016-02-19 Draws temperatures and aircon status nicely
2016-02-25 Cad model tests
    [Backing Piece.SLDPRT, Button.SLDPRT, Controller Assembly.SLDASM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]
2016-10-15 Added rough power monitor
2017-07-21 Added mostly working 3 phase power monitoring code for ATM90E36 with photon.
2017-08-01 Created simple temp/humidity sensor node to report to MQTT server.
2017-08-05 Fleshed out some additional power sampling functions now that the clamps are all installed
2017-08-06 Added backup copies of working openhab configuration files
    [mqtt-eventbus.cfg, mqtt.cfg]
2017-09-11 Reworked the way rain is measured. Uses CHANGE interrupts instead of falling edge, and ensures that the switch opening is within a valid timing window. This should prevent ghost rain readings due to 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
    [WeatherStation.ino]
2018-01-05 Added sampling, calibrated curve and firmware for rainwater tank level sensing. Outputs depth of probe in mm to MQTT server.
2018-01-06 Proper desktop IDE project with deps for watermon Converted to runningAverage for longer term filtered data.
2018-01-07 Reworked water sensing publish timing and buffer size
    [WaterMonitor.ino]
2018-01-07 Reverted change to wind averaging sample buffer size
    [WeatherStation.ino]
2018-01-13 Recalibrated voltage and current sensing. Reformatted and cleanup
2019-02-23 Updated openhab config files with latest from pi
    [addons.cfg, dashboard.cfg, http.cfg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]
